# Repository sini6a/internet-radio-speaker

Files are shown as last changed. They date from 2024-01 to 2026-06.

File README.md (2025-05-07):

# Open Source Internet Radio Player

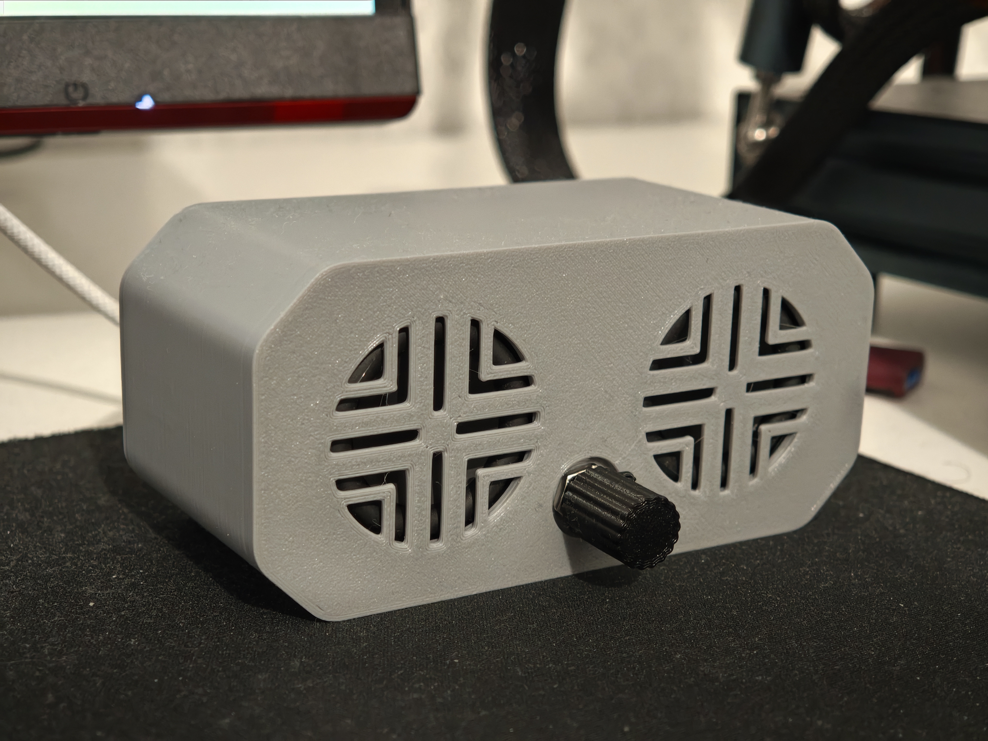
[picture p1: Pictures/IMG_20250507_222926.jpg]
Case #1

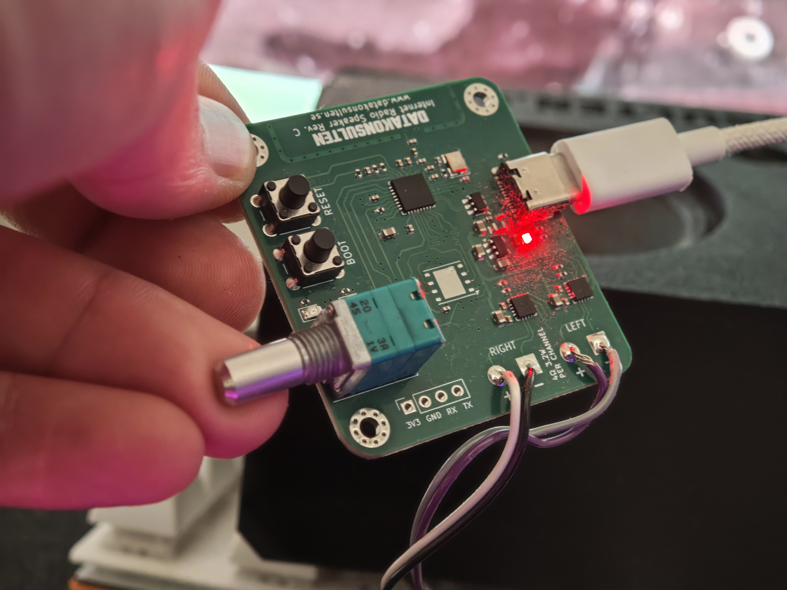
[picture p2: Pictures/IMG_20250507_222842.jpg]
PCB #1
  

## Hardware Specifications

- **Microcontroller:** ESP32-C3
- **Power Supply:** 5V/0.5A (USB Type-C, ~2.5W)
- **Flash Memory:** 4Mbit QSPI (on-chip)
- **Antenna:** Integrated PCB antenna
- **Controls:** Power switch and analog volume potentiometer
- **Audio Output:** Dual speaker output (3.2W max per channel)
- **Indicators:** 3x LEDs (Wi-Fi, Playback, Power)

## Description

This project is a compact, ESP32-C3-based Internet Radio Player designed for ease of use and straightforward integration. The device supports Wi-Fi streaming of MP3 audio and includes basic control via a single potentiometer and button. Audio output is handled via I2S to a stereo amplifier. 

The hardware includes onboard status LEDs and is powered via USB Type-C. It's suitable for low-power audio streaming applications, DIY audio projects, or integration into custom enclosures.

## Features

- 2.4 GHz Wi-Fi support using the built-in PCB antenna
- Minimal controls for simple user interaction
- USB Type-C programming and power interface
- Stereo speaker output via digital I2S
- LED indicators for connection and playback status

## Firmware and Usage

The firmware is located in the `Firmware/` directory and is built using the Arduino framework. Upload it via the Arduino IDE or other compatible tools. 

### Initial Setup

1. Flash the firmware to the ESP32-C3.
2. On first boot, the device creates a Wi-Fi Access Point.
3. Connect to the AP to configure the Wi-Fi credentials and stream URL.
4. After setup, the device reboots into streaming mode.

## Status

- Current hardware revision is stable and has been tested.
- The device is functional and ready for personal assembly or integration.
- Further development (BLE config, web UI, OTA, etc.) is planned or ongoing.

## Contributions

Pull requests, issue reports, and improvements are welcome. Make sure to open issue before to discuss changes.

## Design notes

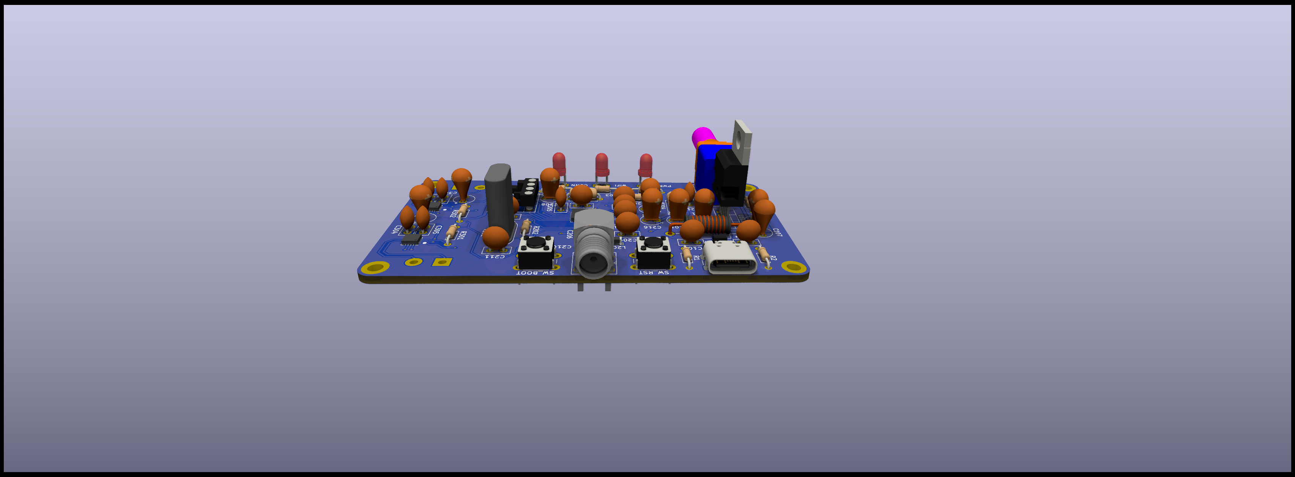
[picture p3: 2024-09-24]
Pictures/revision-2-1.png

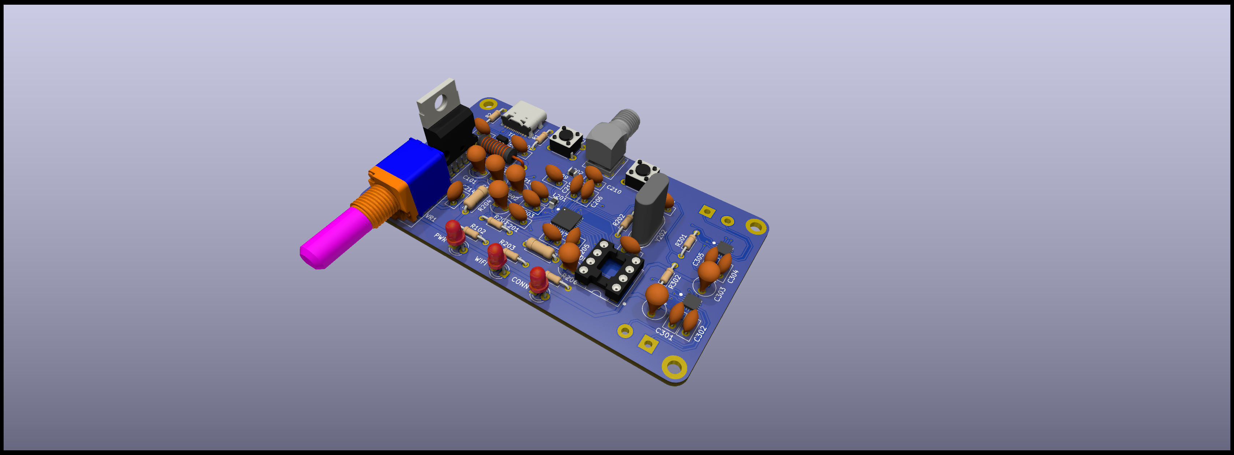
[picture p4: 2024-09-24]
Pictures/revision-2.png

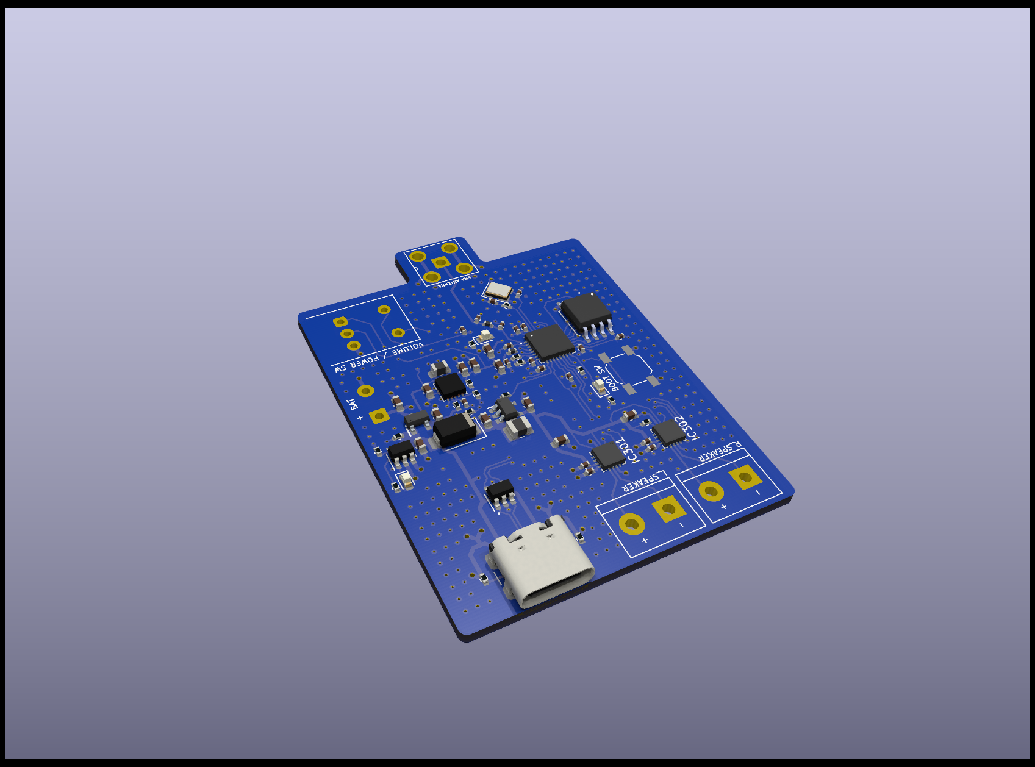
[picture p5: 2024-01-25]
Pictures/internet-radio-speaker-1.png

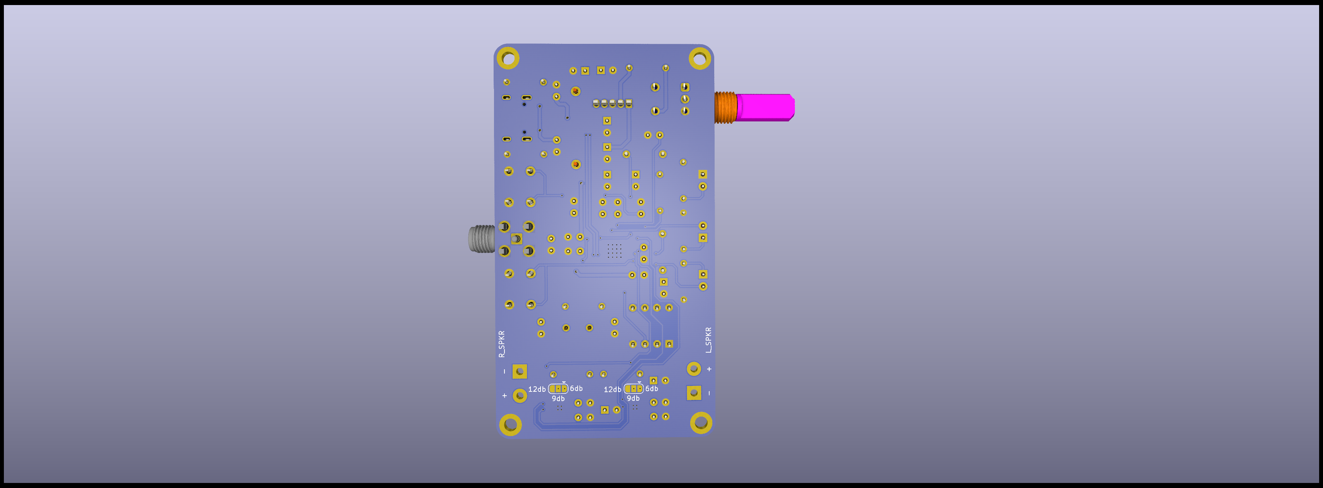
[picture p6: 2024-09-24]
Pictures/revision-2-2.png

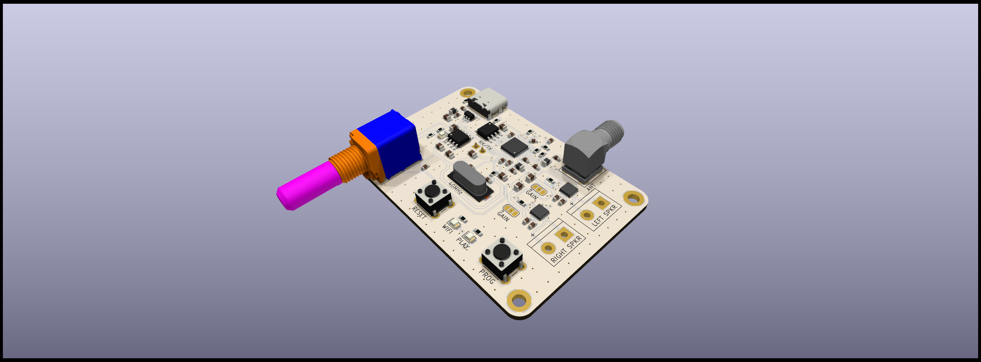
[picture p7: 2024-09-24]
Pictures/revision-3.png

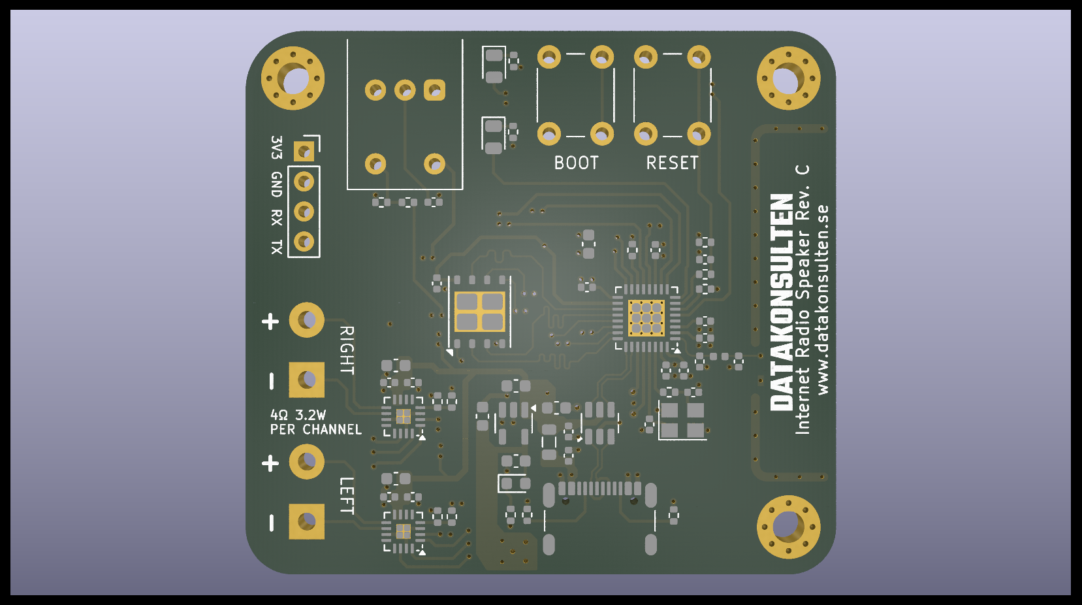
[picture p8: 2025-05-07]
Pictures/revision-4.png

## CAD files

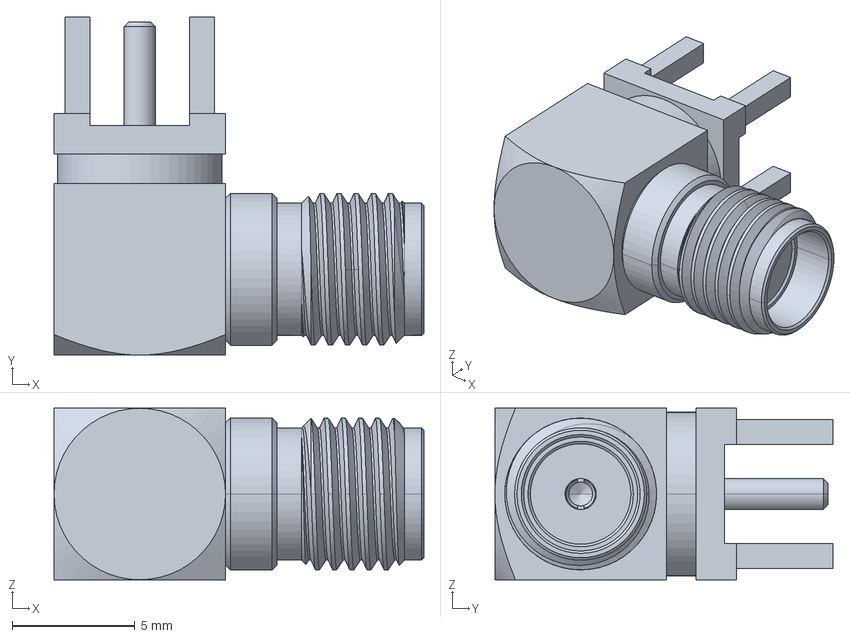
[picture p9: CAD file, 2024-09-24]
KiCad/3d/901-143-6RFX.stp
15.1 x 13.8 x 7.00 mm

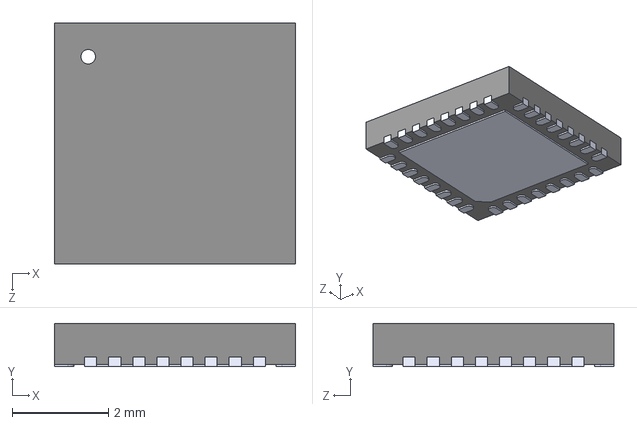
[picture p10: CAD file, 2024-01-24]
KiCad/3d/ESP32C3.step
5.00 x 0.9 x 5.00 mm

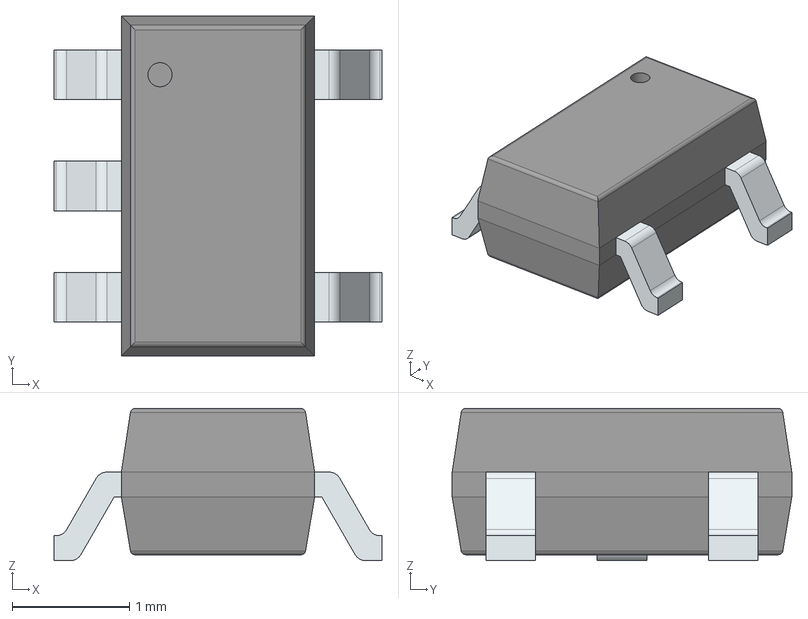
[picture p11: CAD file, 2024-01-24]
KiCad/3d/XC9141B33DMR-G.stp
2.80 x 2.90 x 1.30 mm
PinsArrayL
PinsArrayR

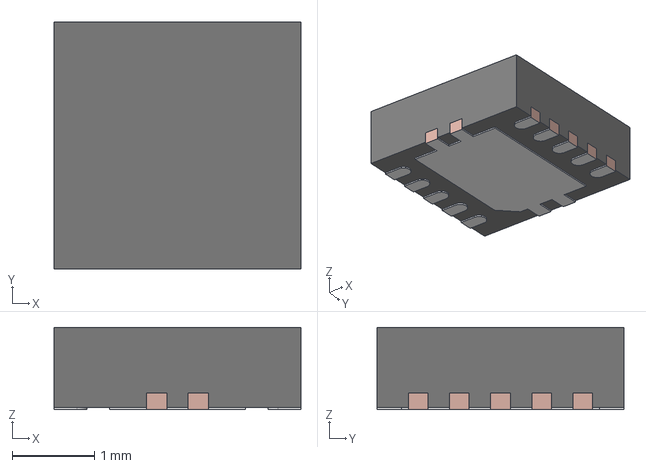
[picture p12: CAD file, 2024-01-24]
KiCad/3d/DRC0010J.stp
3.00 x 3.00 x 1.00 mm
BODY-SON
FRAME-DRC0010J

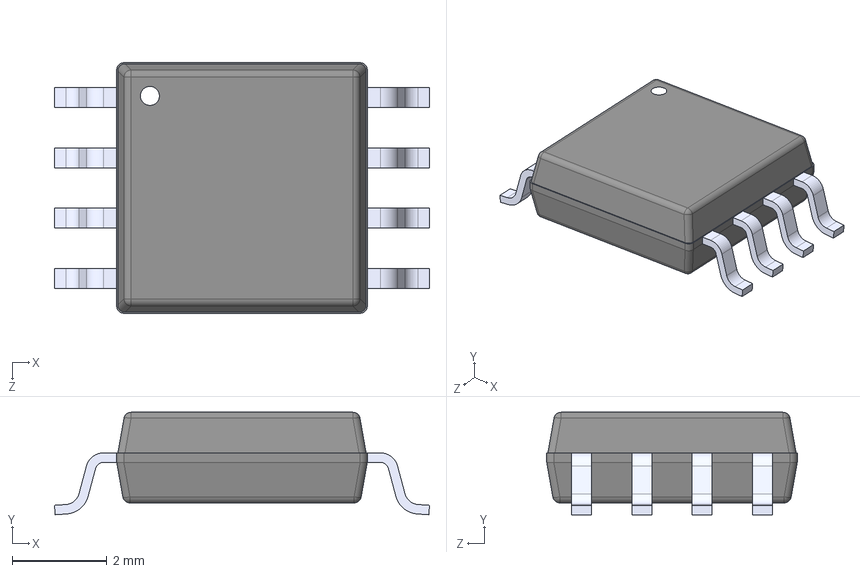
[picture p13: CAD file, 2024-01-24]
KiCad/3d/W25Q32JVSSIQ--3DModel-STEP-269445.STEP
7.90 x 2.16 x 5.28 mm

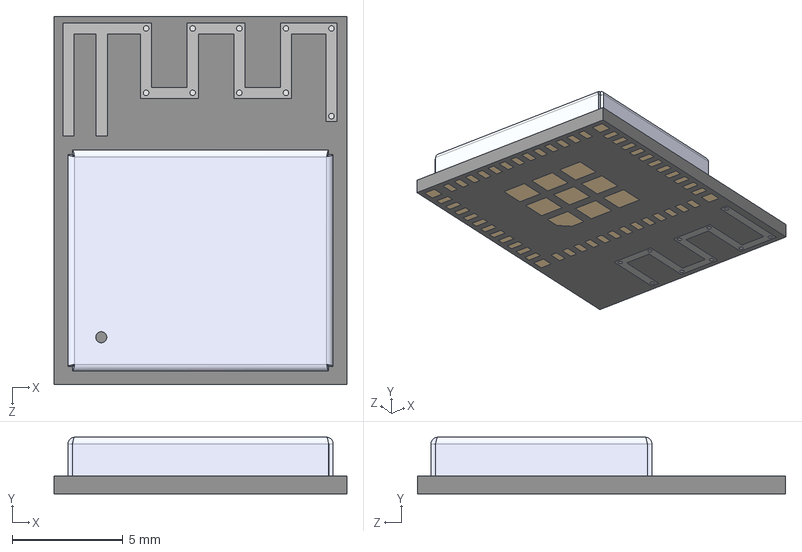
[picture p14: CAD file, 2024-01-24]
KiCad/3d/ESP32-C3-MINI-1-N4.step
13.2 x 2.55 x 16.6 mm

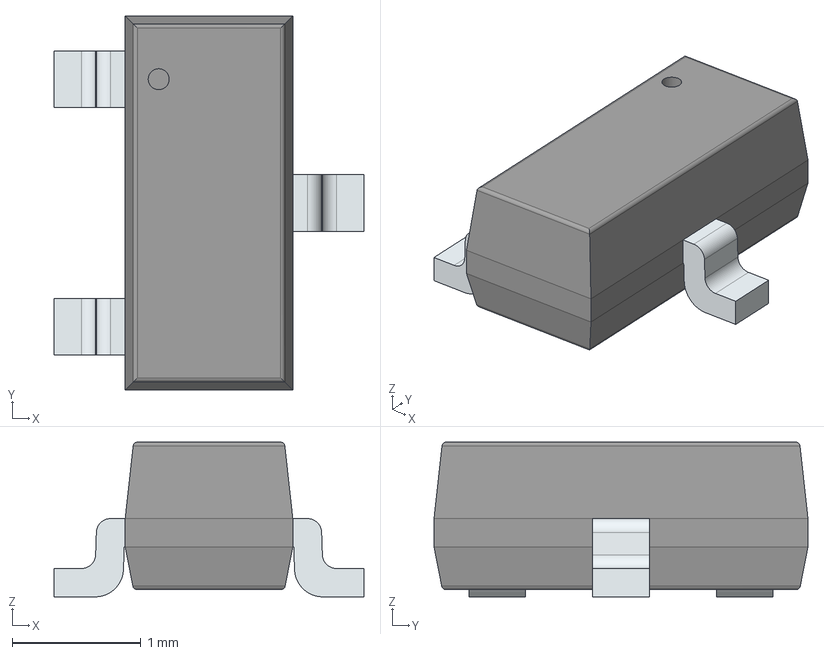
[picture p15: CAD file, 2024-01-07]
KiCad/3d/DMP1045U-7.stp
2.40 x 2.90 x 1.20 mm
PinsArrayL
FilletPinR

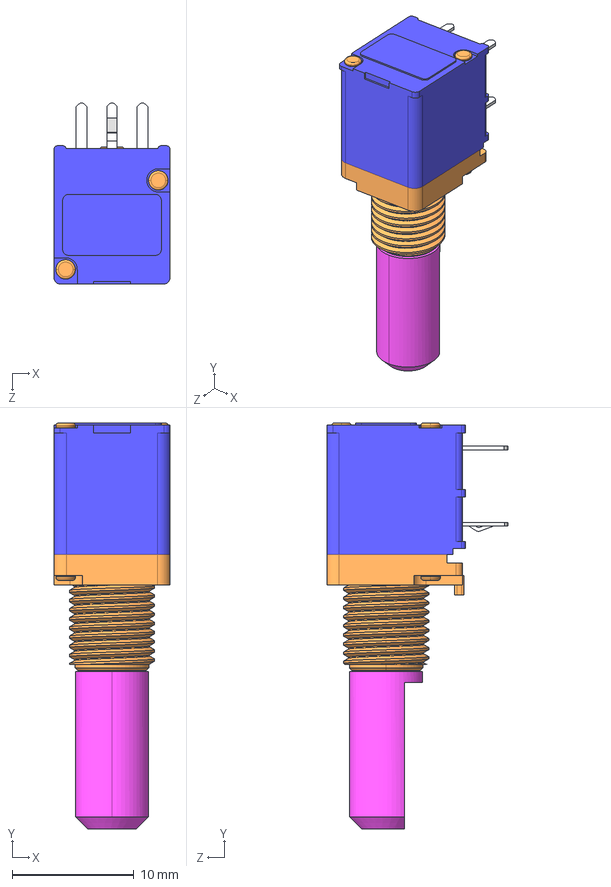
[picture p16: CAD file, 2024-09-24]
KiCad/3d/RK0971111-L20.STEP
9.50 x 33.3 x 14.8 mm

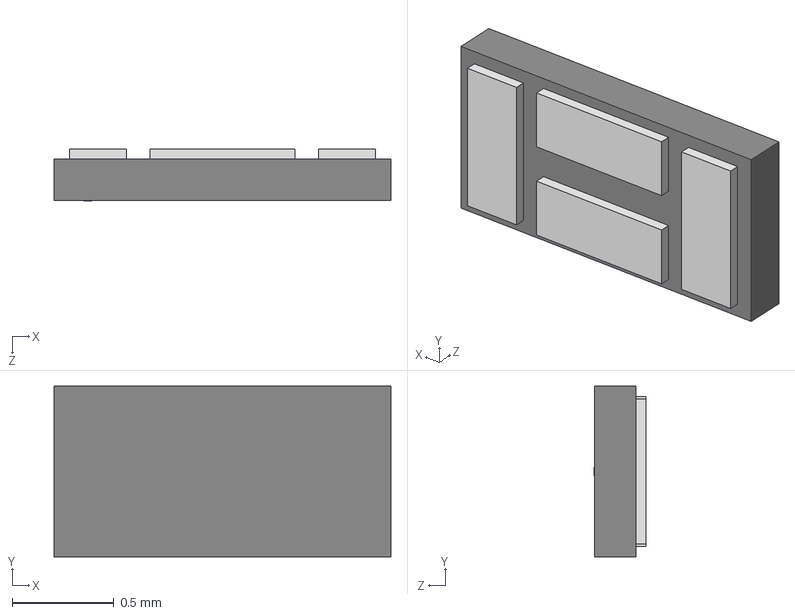
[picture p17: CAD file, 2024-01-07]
KiCad/3d/DLF162500LT-5028A1.stp
1.65 x 0.838 x 0.257 mm

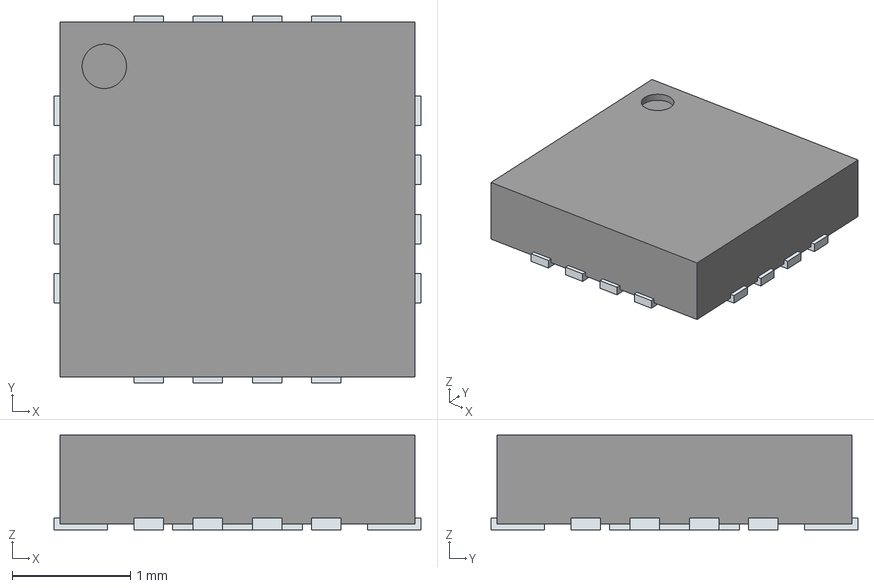
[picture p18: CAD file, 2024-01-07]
KiCad/3d/MAX98357AETE+T.stp
3.10 x 3.10 x 0.8 mm
ThermalPin
PinsArrayLR
PinsArrayTB

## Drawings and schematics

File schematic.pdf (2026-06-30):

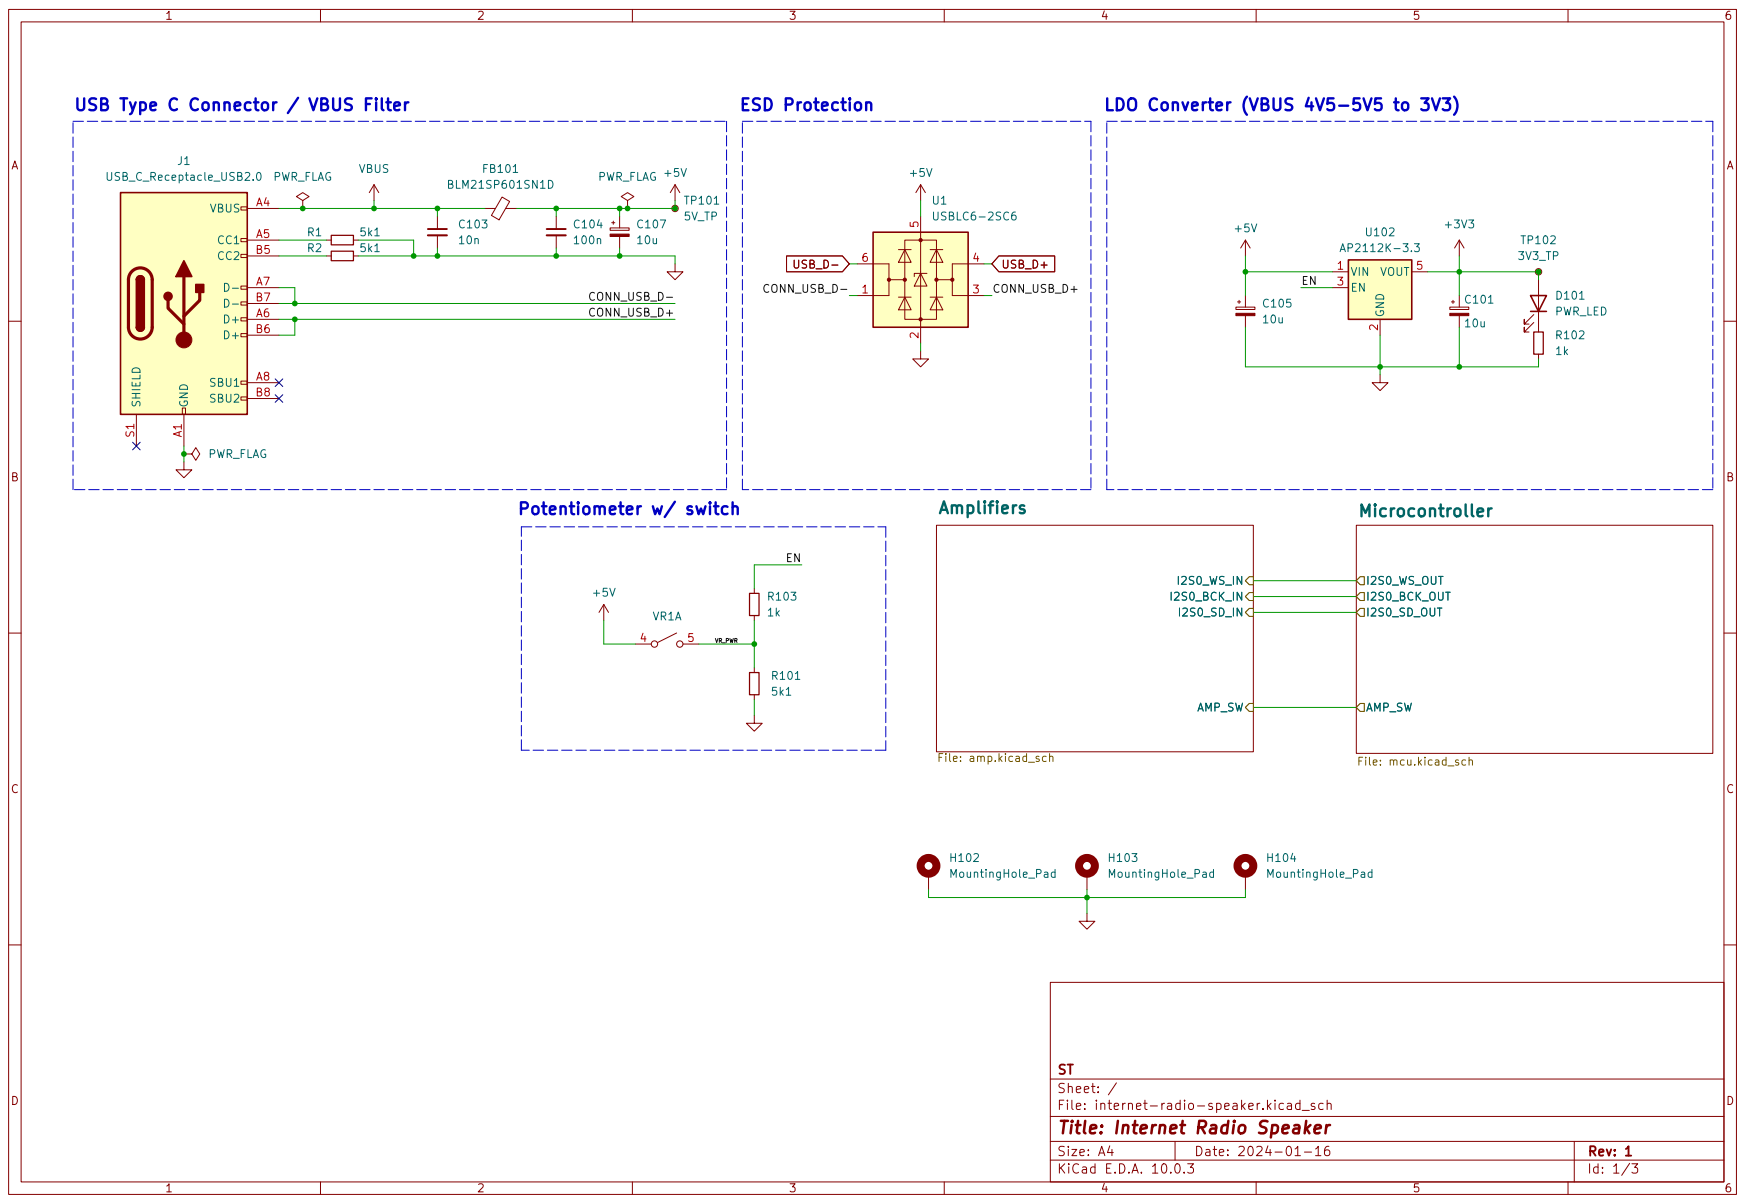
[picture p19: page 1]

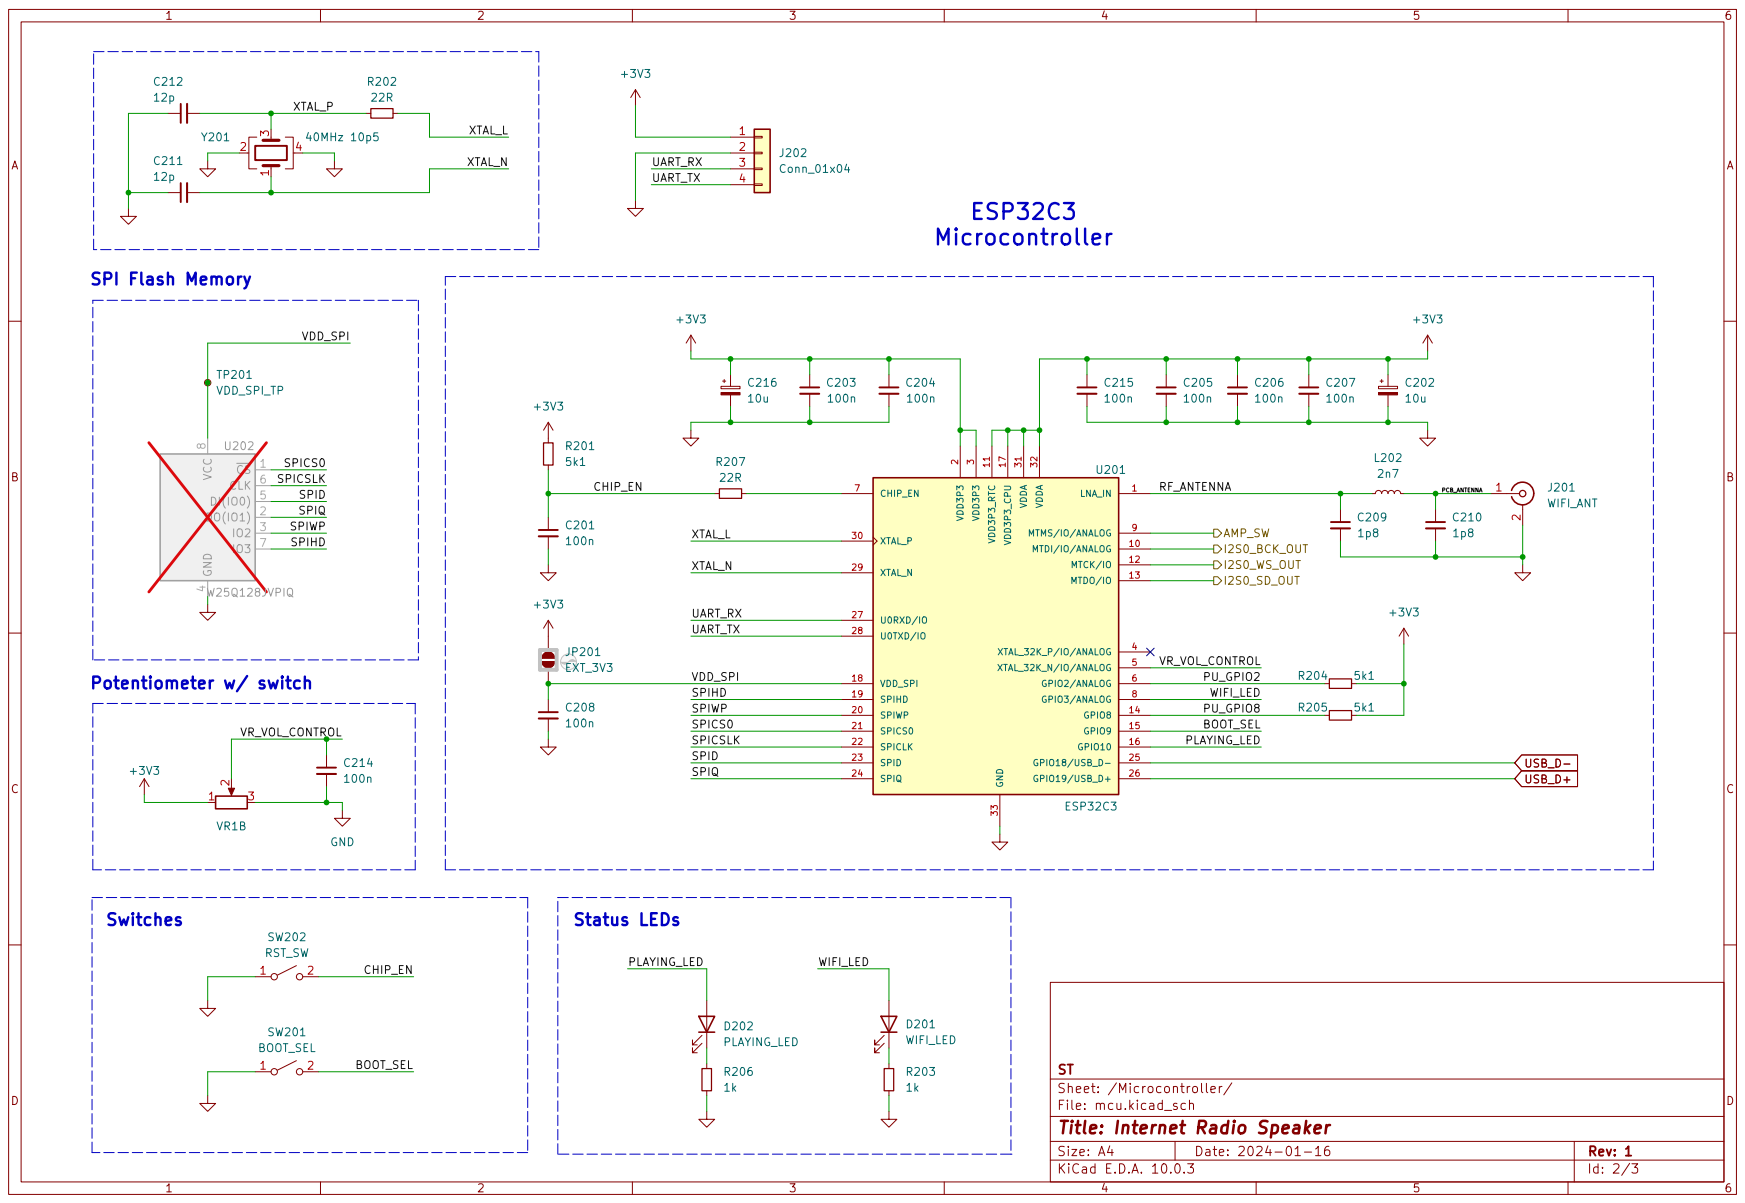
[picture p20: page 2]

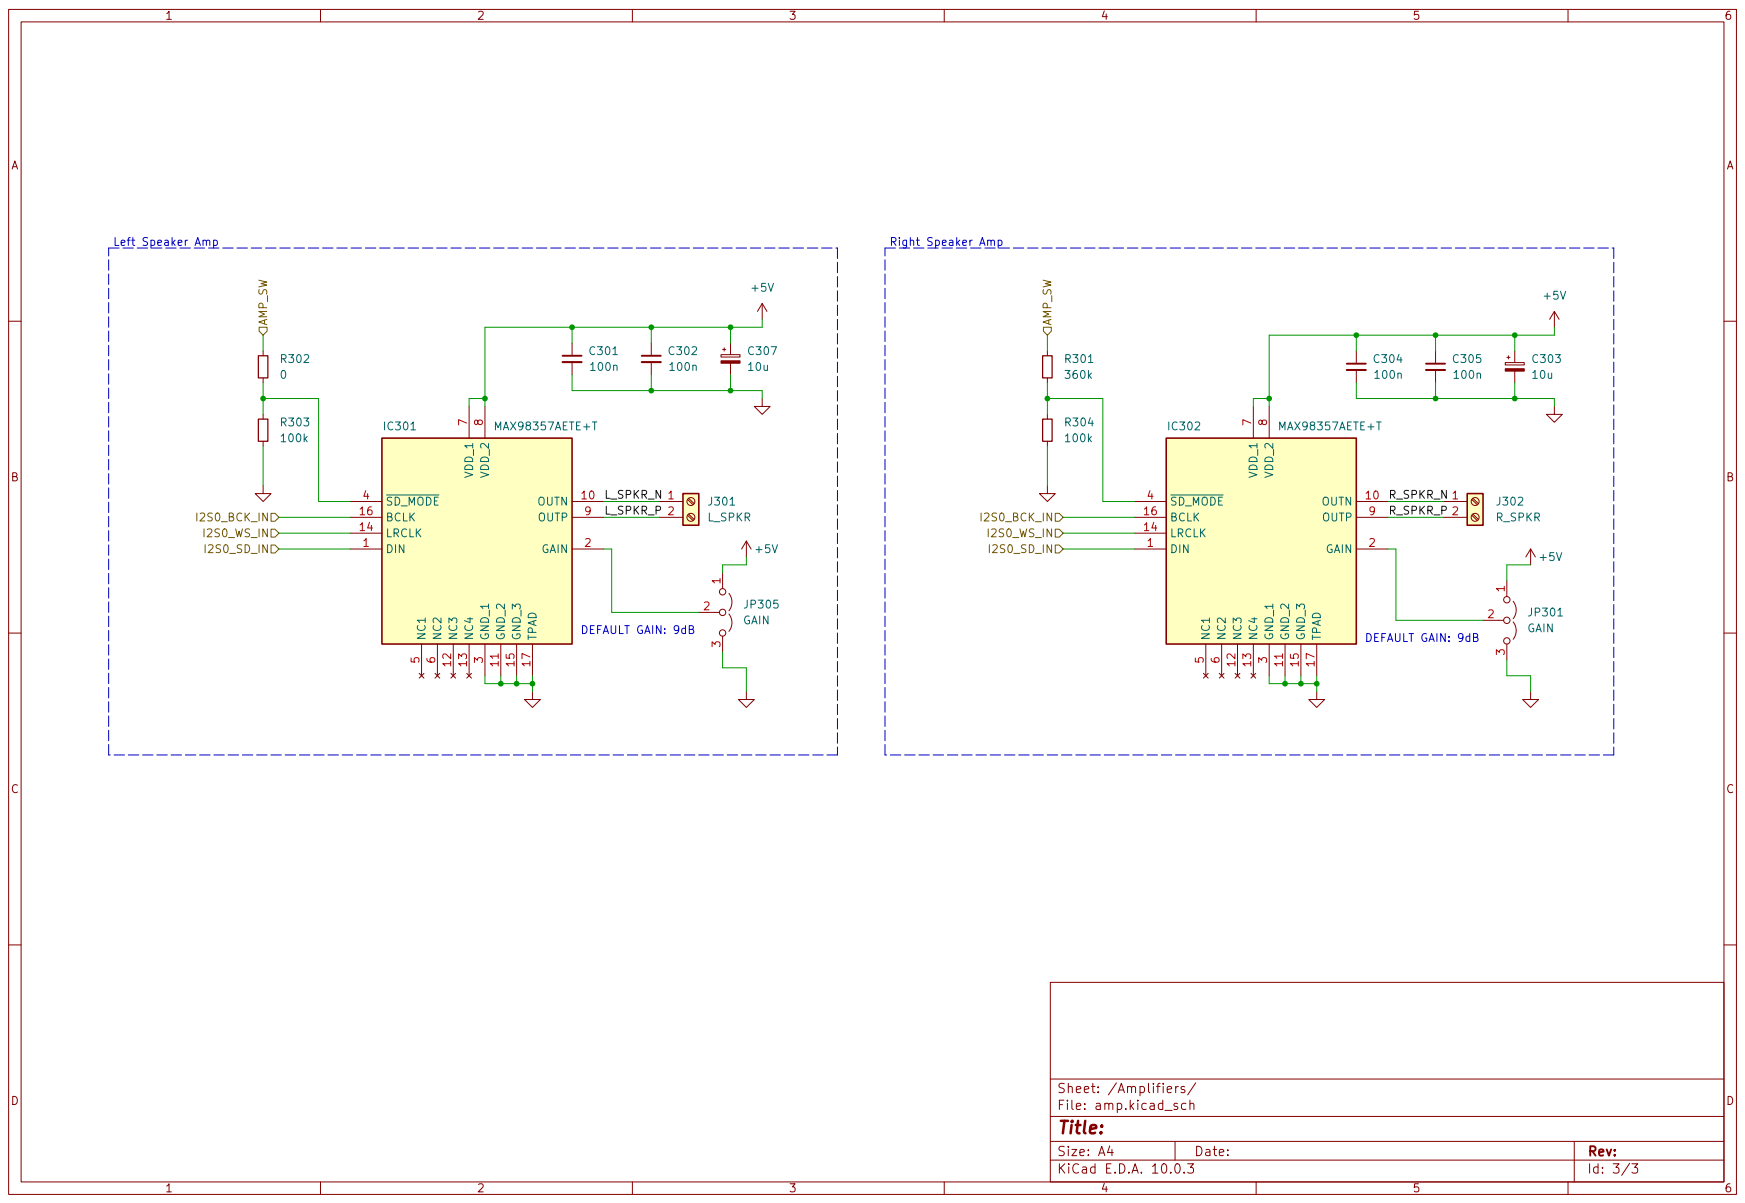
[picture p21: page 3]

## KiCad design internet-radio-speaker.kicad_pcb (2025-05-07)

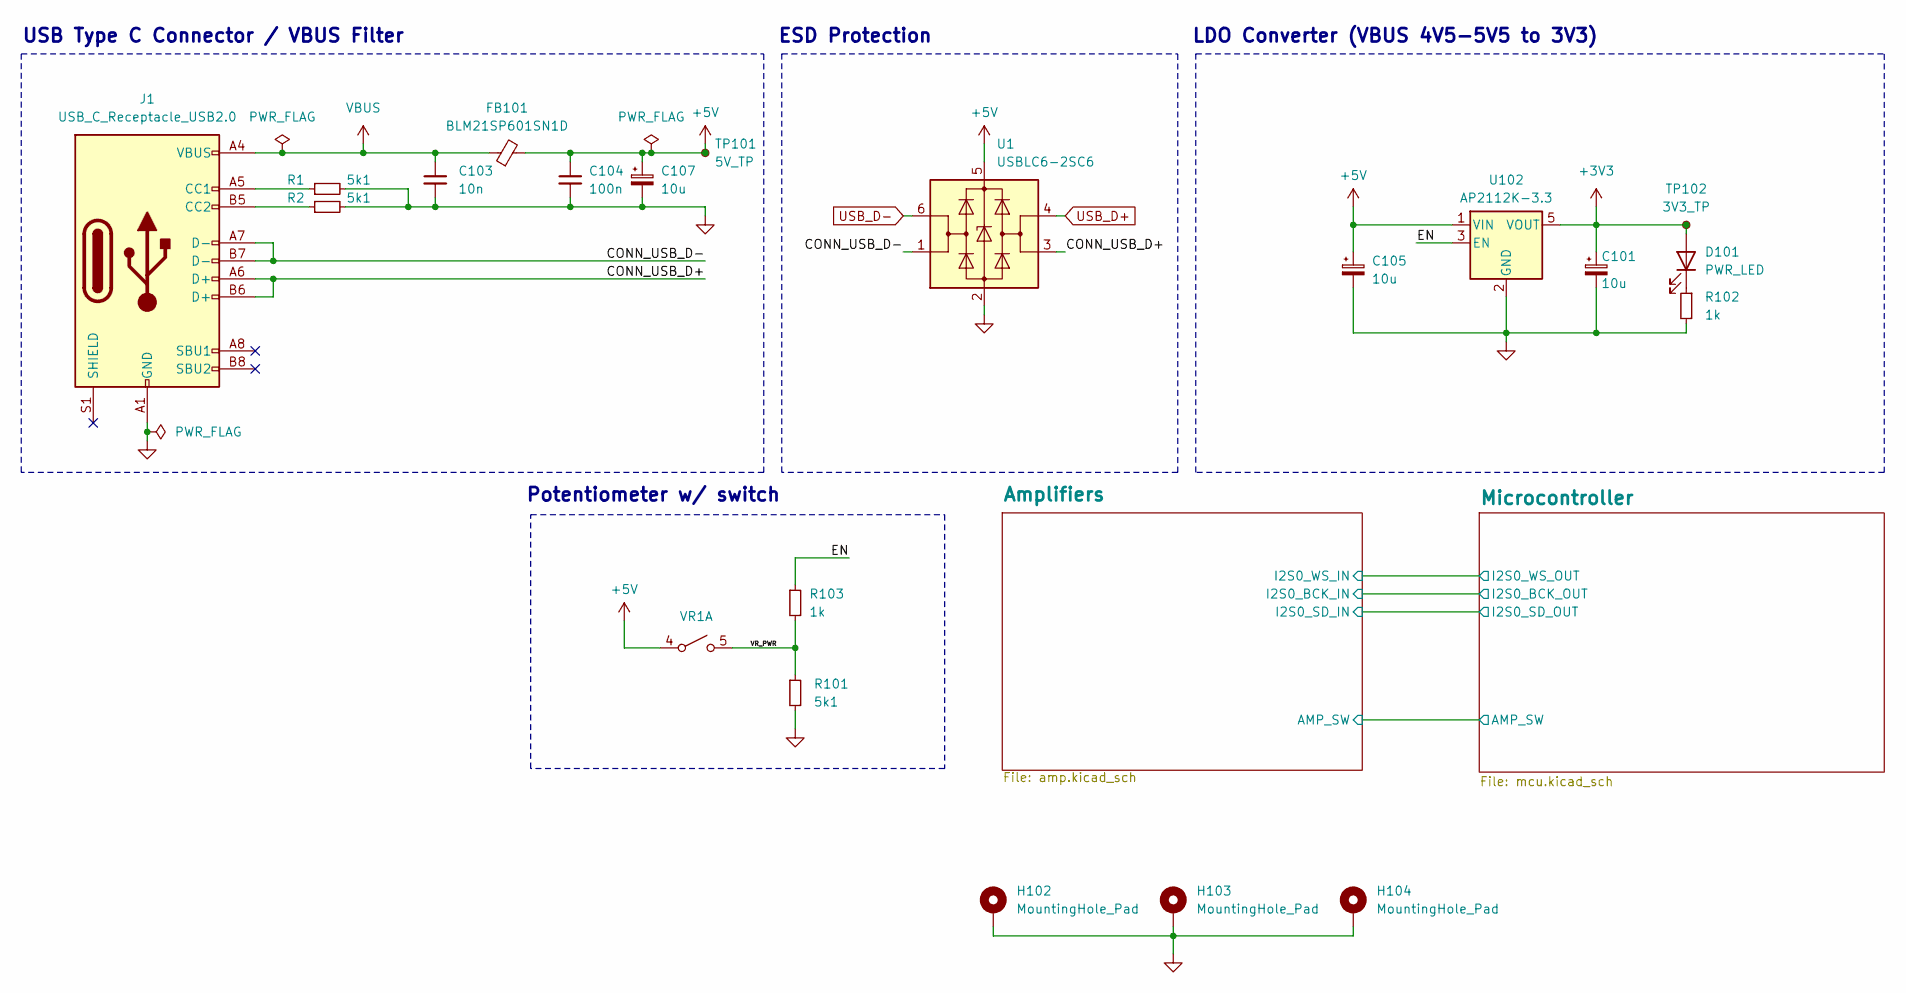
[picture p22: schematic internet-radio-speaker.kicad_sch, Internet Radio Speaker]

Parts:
C101, C105, C107: 10u; C_0603_1608Metric; JLCPCB Part # C96446
C103: 10n; C_0402_1005Metric; JLCPCB Part # C15195
C104: 100n; C_0402_1005Metric; JLCPCB Part # C1525
D101: PWR_LED; LED_0603_1608Metric; JLCPCB Part # C2286
FB101: BLM21SP601SN1D; L_0805_2012Metric; JLCPCB Part # C3716677
H102, H103, H104: MountingHole_Pad; MountingHole_2.7mm_M2.5_Pad_Via
J1: USB_C_Receptacle_USB2.0; USB_C_Receptacle_GCT_USB4105-xx-A_16P_TopMnt_Horizontal; JLCPCB Part # C2927038
R1, R2, R101: 5k1; R_0402_1005Metric; JLCPCB Part # C25905
R102, R103: 1k; R_0402_1005Metric; JLCPCB Part # C11702
TP101: 5V_TP; TestPoint_Pad_D1.5mm
TP102: 3V3_TP; TestPoint_Pad_D1.5mm
U1: USBLC6-2SC6; SOT-23-6; JLCPCB Part # C2687116
U102: AP2112K-3.3; SOT-23-5; JLCPCB Part # C51118
VR1: Potentiometer_Alps_RK0971111Z1P; JLCPCB Part # C2687318

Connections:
+3V3: C101.1, D101.2 (A), TP102.1, U102.5 (VOUT); also elsewhere on the board
+5V: C104.1, C105.1, C107.1, FB101.2, TP101.1, U1.5 (VBUS), U102.1 (VIN), VR1.4 (A); also elsewhere on the board
/CONN_USB_D+: J1.A6 (D+), J1.B6 (D+), U1.3 (I/O2)
/CONN_USB_D-: J1.A7 (D-), J1.B7 (D-), U1.1 (I/O1)
/EN: R103.1, U102.3 (EN)
/VR_PWR: R101.1, R103.2, VR1.5 (B)
GND: C101.2, C103.2, C104.2, C105.2, C107.2, H102.1, H103.1, H104.1, J1.A1 (GND), J1.A12 (GND), J1.B1 (GND), J1.B12 (GND), R1.2, R2.2, R101.2, R102.2, U1.2 (GND), U102.2 (GND); also elsewhere on the board
unnamed: D101.1 (K), R102.1
unnamed: J1.A5 (CC1), R1.1
unnamed: J1.B5 (CC2), R2.1
USB_D+: U1.4 (I/O2); also elsewhere on the board
USB_D-: U1.6 (I/O1); also elsewhere on the board
VBUS: C103.1, FB101.1, J1.A4 (VBUS), J1.A9 (VBUS), J1.B4 (VBUS), J1.B9 (VBUS)

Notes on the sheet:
ESD Protection
USB Type C Connector / VBUS Filter
Potentiometer w/ switch
LDO Converter (VBUS 4V5-5V5 to 3V3)

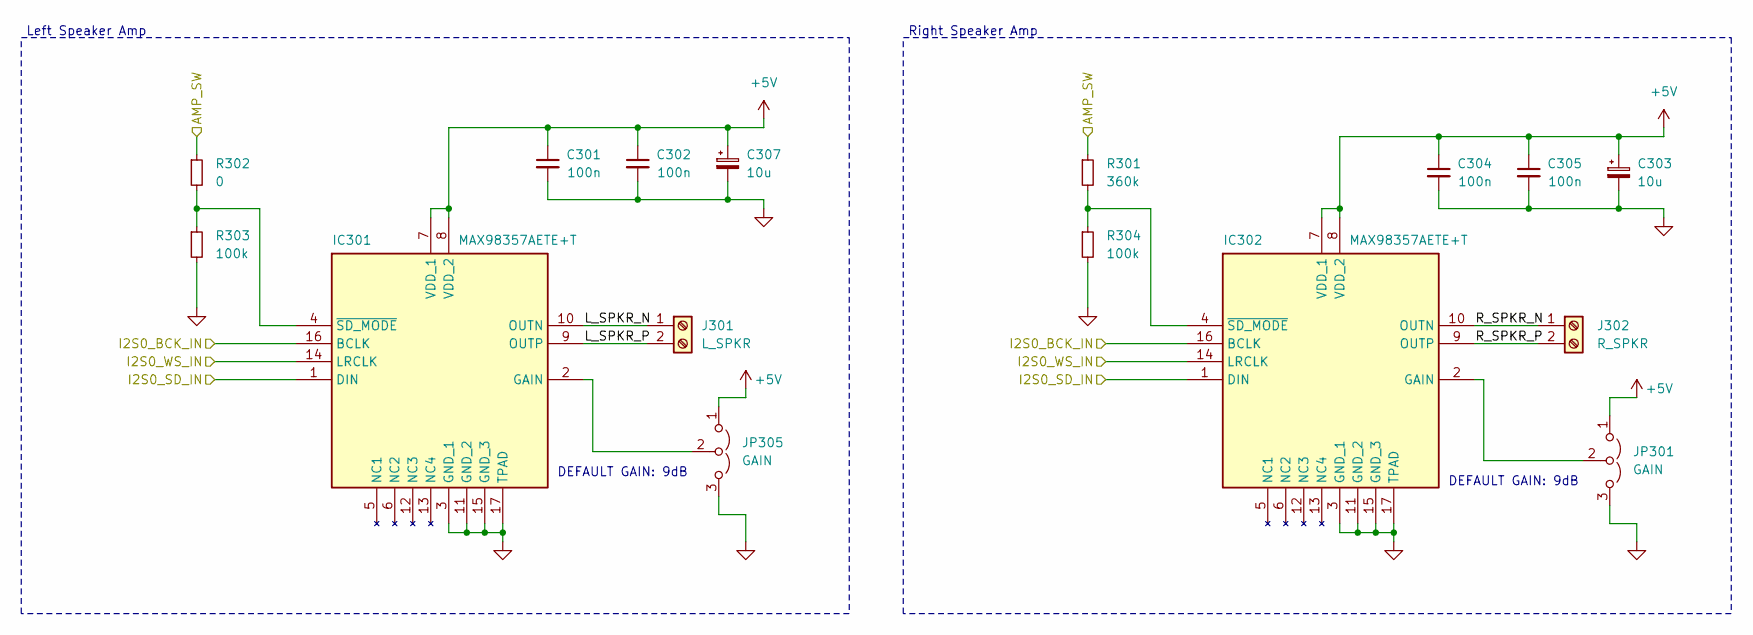
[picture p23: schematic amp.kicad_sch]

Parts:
C301, C302, C304, C305: 100n; C_0402_1005Metric; JLCPCB Part # C1525
C303, C307: 10u; C_0603_1608Metric; JLCPCB Part # C96446
IC301, IC302: MAX98357AETE+T; TQFN-16-1EP_3x3mm_P0.5mm_EP1.23x1.23mm_ThermalVias; JLCPCB Part # C910544
J301: L_SPKR; TerminalBlock_bornier-2_P5.08mm
J302: R_SPKR; TerminalBlock_bornier-2_P5.08mm
JP301, JP305: GAIN; SolderJumper-3_P1.3mm_Open_RoundedPad1.0x1.5mm
R301: 360k; R_0402_1005Metric; JLCPCB Part # C45956
R302: 0; R_0402_1005Metric; JLCPCB Part # C17168
R303, R304: 100k; R_0402_1005Metric; JLCPCB Part # C25741

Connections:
+5V: C301.1, C302.1, C303.1, C304.1, C305.1, C307.1, IC301.7 (VDD_1), IC301.8 (VDD_2), IC302.7 (VDD_1), IC302.8 (VDD_2), JP301.1 (A), JP305.1 (A); also elsewhere on the board
/Amplifiers/AMP_SW: R301.1, R302.1; also elsewhere on the board
/Amplifiers/I2S0_BCK_IN: IC301.16 (BCLK), IC302.16 (BCLK); also elsewhere on the board
/Amplifiers/I2S0_SD_IN: IC301.1 (DIN), IC302.1 (DIN); also elsewhere on the board
/Amplifiers/I2S0_WS_IN: IC301.14 (LRCLK), IC302.14 (LRCLK); also elsewhere on the board
/Amplifiers/L_SPKR_N: IC301.10 (OUTN), J301.1
/Amplifiers/L_SPKR_P: IC301.9 (OUTP), J301.2
/Amplifiers/R_SPKR_N: IC302.10 (OUTN), J302.1
/Amplifiers/R_SPKR_P: IC302.9 (OUTP), J302.2
GND: C301.2, C302.2, C303.2, C304.2, C305.2, C307.2, IC301.3 (GND_1), IC301.11 (GND_2), IC301.15 (GND_3), IC301.17 (TPAD), IC302.3 (GND_1), IC302.11 (GND_2), IC302.15 (GND_3), IC302.17 (TPAD), JP301.3 (B), JP305.3 (B), R303.2, R304.2; also elsewhere on the board
unnamed: IC301.2 (GAIN), JP305.2 (C)
unnamed: IC301.4 (~SD_MODE), R302.2, R303.1
unnamed: IC302.2 (GAIN), JP301.2 (C)
unnamed: IC302.4 (~SD_MODE), R301.2, R304.1

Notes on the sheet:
Left Speaker Amp
Right Speaker Amp
DEFAULT GAIN: 9dB

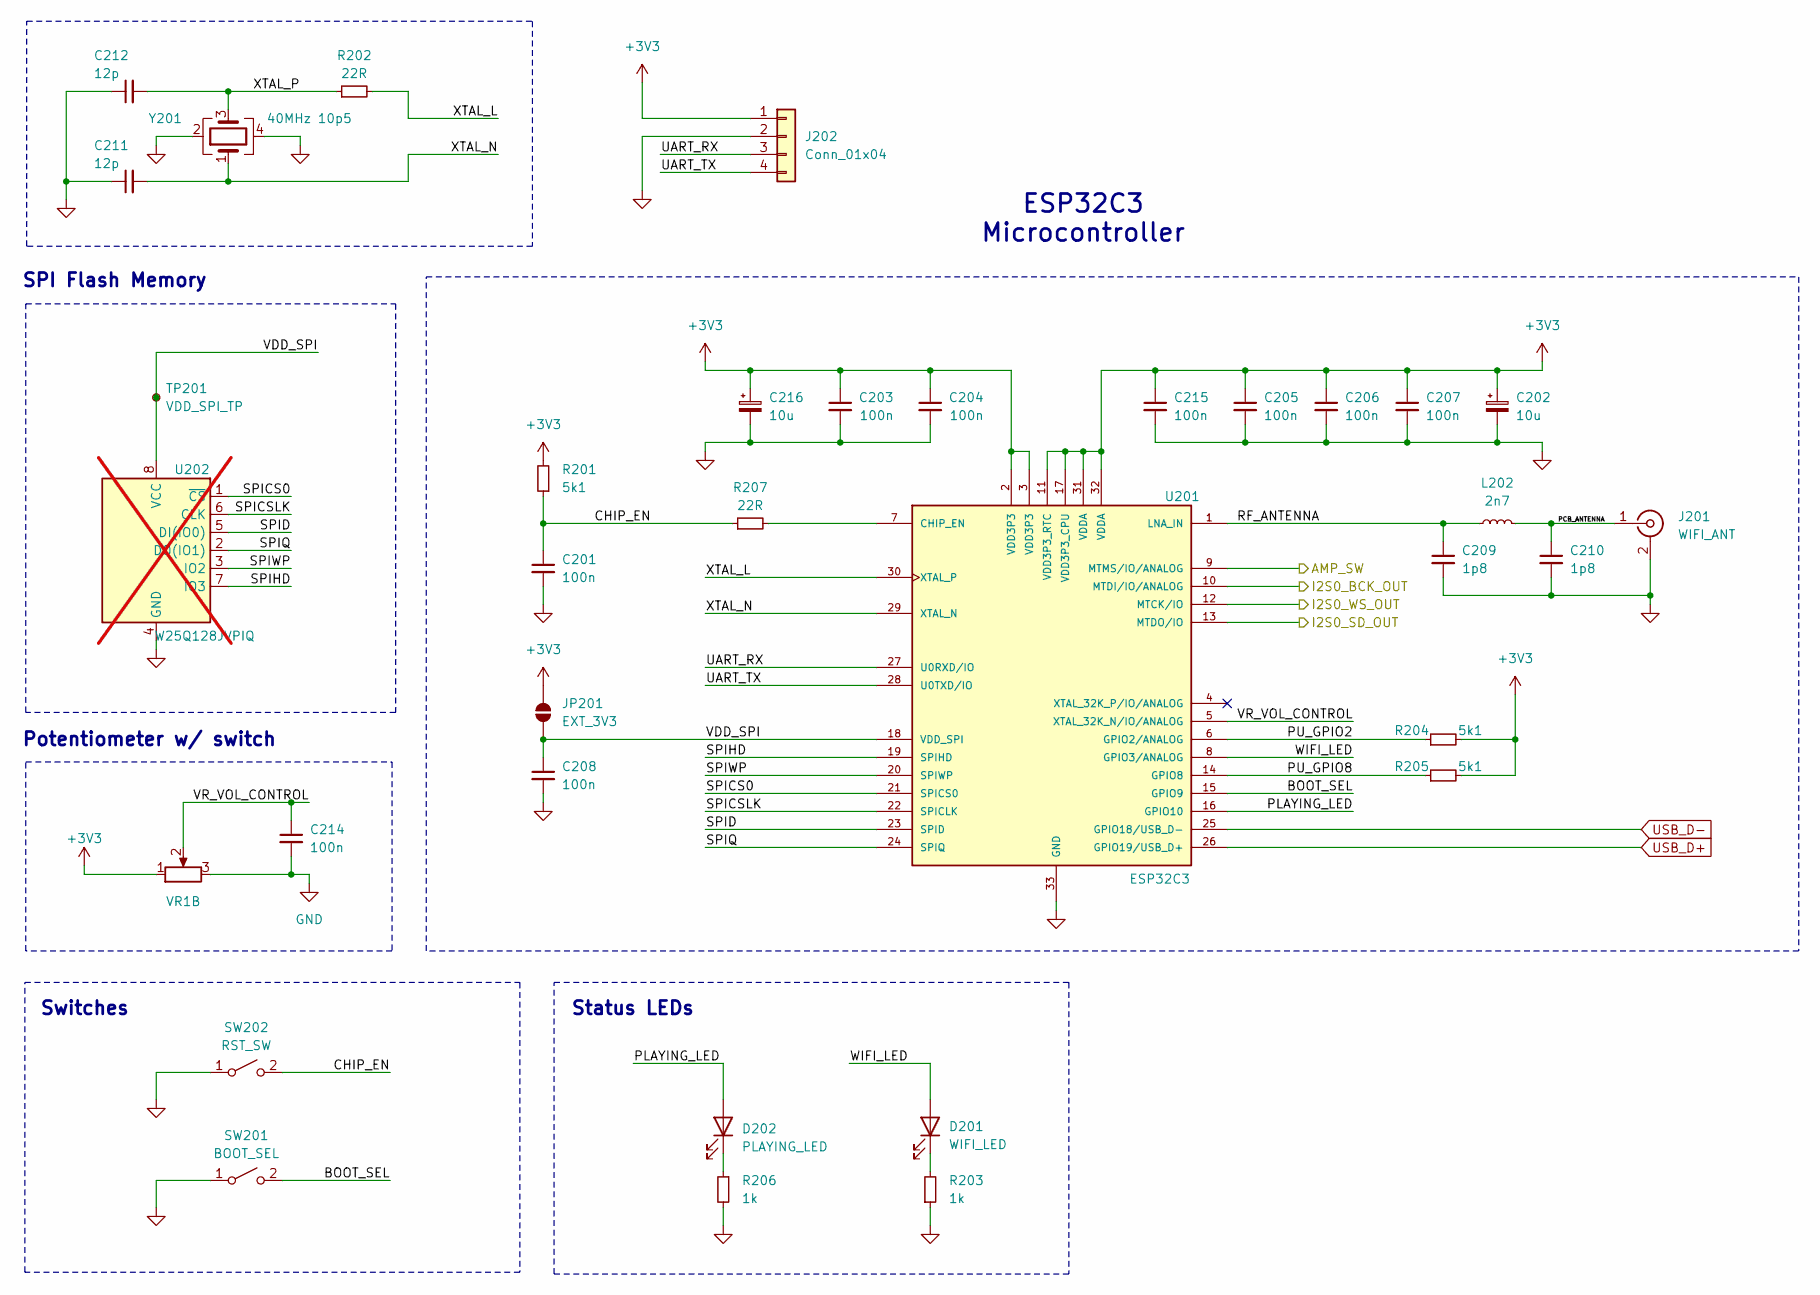
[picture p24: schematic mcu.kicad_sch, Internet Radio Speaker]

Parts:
C201, C203, C204, C205, C206, C207, C208, C214, C215: 100n; C_0402_1005Metric; JLCPCB Part # C1525
C202, C216: 10u; C_0603_1608Metric; JLCPCB Part # C96446
C209, C210: 1p8; C_0402_1005Metric; JLCPCB Part # C1553
C211, C212: 12p; C_0402_1005Metric; JLCPCB Part # C1547
D201: WIFI_LED; LED_0805_2012Metric; JLCPCB Part # C2297
D202: PLAYING_LED; LED_0805_2012Metric; JLCPCB Part # C2296
J201: WIFI_ANT; Texas_SWRA117D_2.4GHz_Right; LCSC C3174435
J202: Conn_01x04; PinSocket_1x04_P2.54mm_Vertical
JP201: EXT_3V3; SolderJumper-2_P1.3mm_Open_RoundedPad1.0x1.5mm
L202: 2n7; L_0402_1005Metric; JLCPCB Part # C77108
R201, R204, R205: 5k1; R_0402_1005Metric; JLCPCB Part # C25905
R202, R207: 22R; R_0402_1005Metric; JLCPCB Part # C25092
R203, R206: 1k; R_0402_1005Metric; JLCPCB Part # C11702
SW201: BOOT_SEL; SW_PUSH_6mm; JLCPCB Part # C2889001
SW202: RST_SW; SW_PUSH_6mm; JLCPCB Part # C2889001
TP201: VDD_SPI_TP; TestPoint_Pad_D1.5mm
U201: ESP32C3; HVQFN-32-1EP_5x5mm_P0.5mm_EP3.1x3.1mm_ThermalVias; LCSC C2858491
U202: W25Q128JVPIQ; WSON-8-1EP_6x5mm_P1.27mm_EP3.4x4.3mm; JLCPCB Part # C190862; not fitted
VR1: Potentiometer_Alps_RK0971111Z1P; JLCPCB Part # C2687318
Y201: 40MHz 10p5; Crystal_SMD_3225-4Pin_3.2x2.5mm; JLCPCB Part # C19191260

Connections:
+3V3: C202.1, C203.1, C204.1, C205.1, C206.1, C207.1, C215.1, C216.1, J202.1, JP201.2 (B), R201.2, R204.2, R205.2, U201.2 (VDD3P3), U201.3 (VDD3P3), U201.11 (VDD3P3_RTC), U201.17 (VDD3P3_CPU), U201.31 (VDDA), U201.32 (VDDA), VR1.1; also elsewhere on the board
/Amplifiers/AMP_SW: U201.9 (MTMS/IO/ANALOG); also elsewhere on the board
/Amplifiers/I2S0_BCK_IN: U201.10 (MTDI/IO/ANALOG); also elsewhere on the board
/Amplifiers/I2S0_SD_IN: U201.13 (MTDO/IO); also elsewhere on the board
/Amplifiers/I2S0_WS_IN: U201.12 (MTCK/IO); also elsewhere on the board
/Microcontroller/BOOT_SEL: SW201.2 (B), U201.15 (GPIO9)
/Microcontroller/CHIP_EN: C201.1, R201.1, R207.1, SW202.2 (B)
/Microcontroller/PCB_ANTENNA: C210.1, J201.1 (In), L202.2
/Microcontroller/PLAYING_LED: D202.2 (A), U201.16 (GPIO10)
/Microcontroller/PU_GPIO2: R204.1, U201.6 (GPIO2/ANALOG)
/Microcontroller/PU_GPIO8: R205.1, U201.14 (GPIO8)
/Microcontroller/RF_ANTENNA: C209.1, L202.1, U201.1 (LNA_IN)
/Microcontroller/SPICS0: U201.21 (SPICS0), U202.1 (~CS)
/Microcontroller/SPICSLK: U201.22 (SPICLK), U202.6 (CLK)
/Microcontroller/SPID: U201.23 (SPID), U202.5 (DI(IO0))
/Microcontroller/SPIHD: U201.19 (SPIHD), U202.7 (IO3)
/Microcontroller/SPIQ: U201.24 (SPIQ), U202.2 (DO(IO1))
/Microcontroller/SPIWP: U201.20 (SPIWP), U202.3 (IO2)
/Microcontroller/UART_RX: J202.3, U201.27 (U0RXD/IO)
/Microcontroller/UART_TX: J202.4, U201.28 (U0TXD/IO)
/Microcontroller/VDD_SPI: C208.1, JP201.1 (A), TP201.1, U201.18 (VDD_SPI), U202.8 (VCC)
/Microcontroller/VR_VOL_CONTROL: C214.1, U201.5 (XTAL_32K_N/IO/ANALOG), VR1.2
/Microcontroller/WIFI_LED: D201.2 (A), U201.8 (GPIO3/ANALOG)
/Microcontroller/XTAL_L: R202.2, U201.30 (XTAL_P)
/Microcontroller/XTAL_N: C211.2, U201.29 (XTAL_N), Y201.1
/Microcontroller/XTAL_P: C212.2, R202.1, Y201.3
GND: C201.2, C202.2, C203.2, C204.2, C205.2, C206.2, C207.2, C208.2, C209.2, C210.2, C211.1, C212.1, C214.2, C215.2, C216.2, J201.2 (Ext), J202.2, R203.1, R206.2, SW201.1 (A), SW202.1 (A), U201.33 (GND), U202.4 (GND), VR1.3, Y201.2, Y201.4; also elsewhere on the board
unnamed: D201.1 (K), R203.2
unnamed: D202.1 (K), R206.1
unnamed: R207.2, U201.7 (CHIP_EN)
USB_D+: U201.26 (GPIO19/USB_D+); also elsewhere on the board
USB_D-: U201.25 (GPIO18/USB_D-); also elsewhere on the board

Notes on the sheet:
SPI Flash Memory
Status LEDs
Potentiometer w/ switch
Switches
ESP32C3 Microcontroller

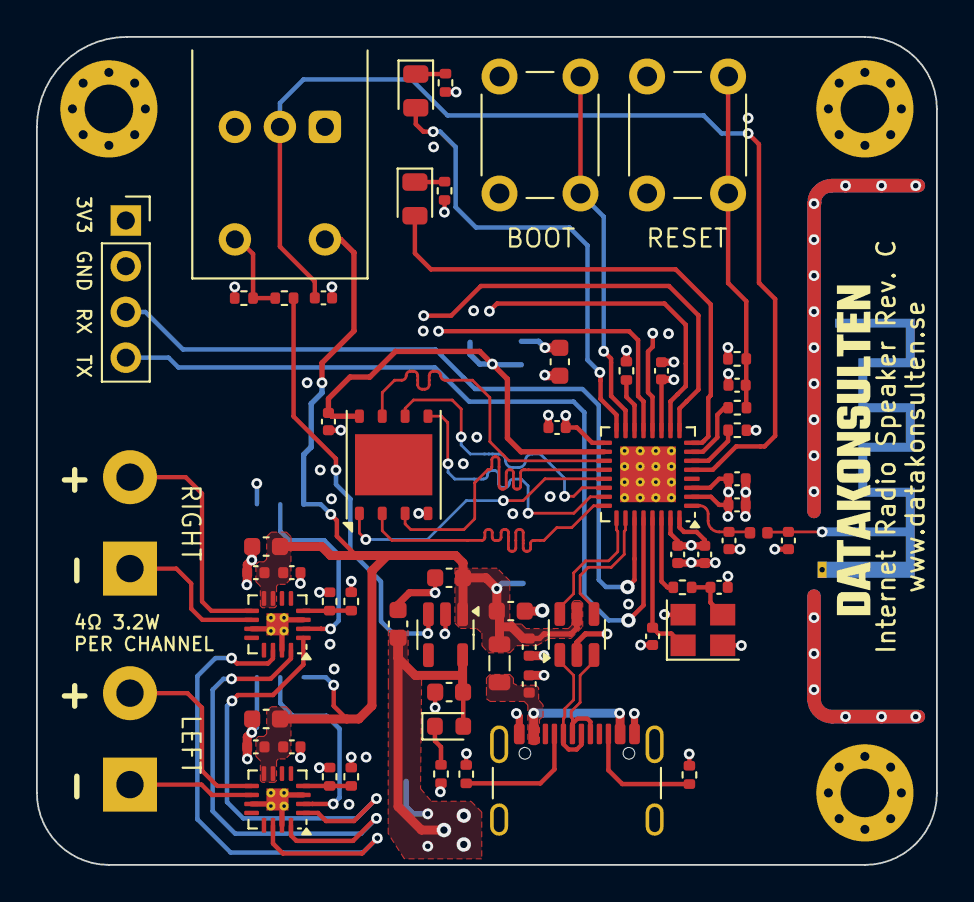
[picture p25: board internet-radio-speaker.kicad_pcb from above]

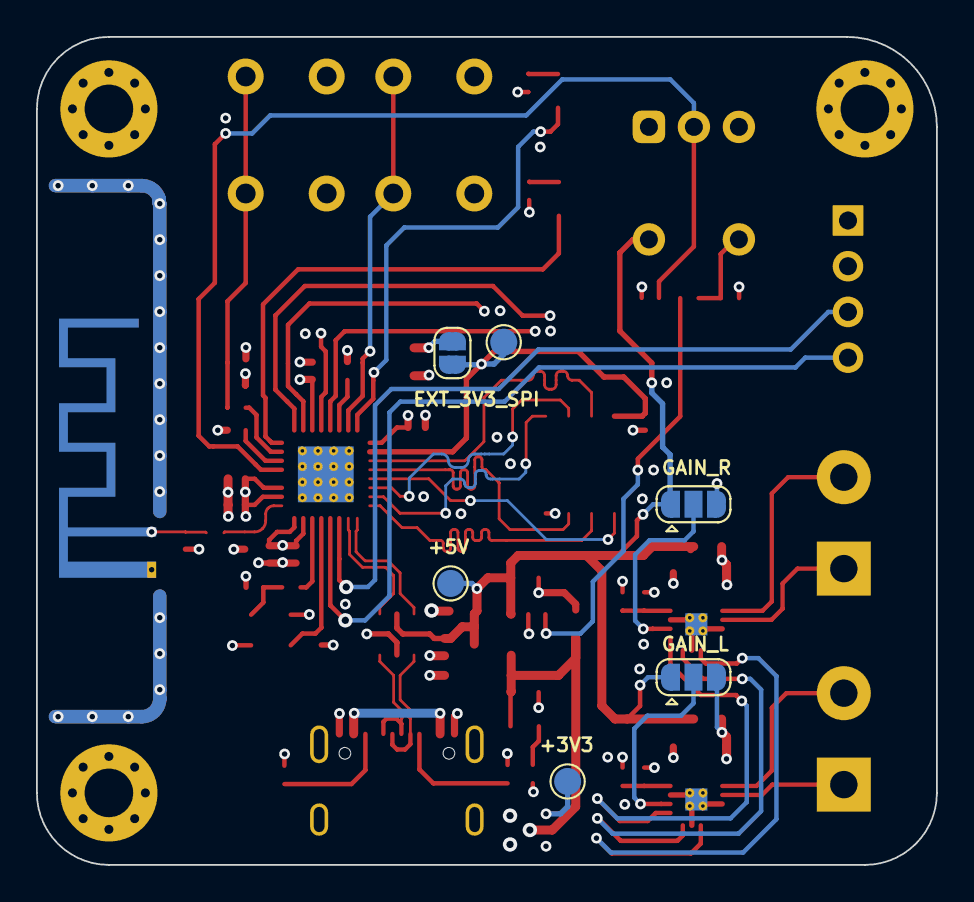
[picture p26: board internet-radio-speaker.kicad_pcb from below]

Board: 4 copper layers, 50.0 x 46.0 mm, 71 parts (7 on the bottom side), 49 nets.

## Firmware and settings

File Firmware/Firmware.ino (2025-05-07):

#define HELIX_FEATURE_AUDIO_CODEC_AAC_SBR
#define AAC_ENABLE_SBR
#define JSON_CONFIG_FILE "/configuration.json"

#include <WiFi.h>
#include <FS.h>
#include <LittleFS.h>
#include <WiFiManager.h>
#include <ArduinoJson.h>
#include "AudioTools.h"
#include "AudioTools/AudioCodecs/CodecMP3Helix.h"

// Constants and Pins
const int AMP_CONTROL_PIN = 4;  // Amplifier control pin (HIGH = ON)
const int WIFI_LED_PIN = 3;     // WiFi status LED
const int MUSIC_LED_PIN = 10;   // Music playing LED
const int VOLUME_CONTROL_PIN = 1;
const int BUTTON_PIN = 9;       // Button GPIO pin
const unsigned long HOLD_TIME = 3000; // Time to hold button for formatting (ms)

// Globals
bool shouldSaveConfig = false;
char streamURL[128] = "http://hyades.shoutca.st:8072/stream.mp3";
WiFiManager wm;
WiFiManagerParameter customTextBox("key_text", "Enter stream URL", streamURL, 128);

// Button Variables
unsigned long buttonPressTime = 0;
bool isFormatting = false;

// Audio Components
URLStream url;
I2SStream i2s;
VolumeStream volume(i2s);
EncodedAudioStream dec(&volume, new MP3DecoderHelix());
StreamCopy copier(dec, url);

// Function Prototypes
bool initializeFileSystem();
void saveConfigFile();
bool loadConfigFile();
void saveConfigCallback();
void configModeCallback(WiFiManager *myWiFiManager);
void initializePins();
void initializeAudio();
void startConfigurationPortal();

// Pre-save callback function
void preSaveConfigCallback() {
    Serial.println("Pre-save callback triggered");
    // Perform any operations before saving, such as checking or modifying values
    shouldSaveConfig = true;
    // Optionally modify any parameters before saving (e.g., update URL)
    // Serial.println("Stream URL: ");
    // Serial.println(streamURL); // You can print or modify values
}

void setup() {
    Serial.begin(115200);

    // Initialize File System
    if (!initializeFileSystem()) {
        Serial.println("Failed to initialize or format the file system. Restarting...");
        ESP.restart();
    }

    // Load Configuration
    bool forceConfig = !loadConfigFile();
    if (forceConfig) {
        Serial.println("Forcing configuration mode due to missing or invalid config.");
    }

    // Initialize button pin
    pinMode(BUTTON_PIN, INPUT_PULLUP);

    // Check if button is pressed at boot
    if (digitalRead(BUTTON_PIN) == LOW) {
        forceConfig = true;
    }

    // Audio Logger
    //AudioLogger::instance().begin(Serial, AudioLogger::Info);

    // Setup WiFi Manager
    WiFi.mode(WIFI_STA);
    wm.setSaveConfigCallback(saveConfigCallback);
    wm.setSaveParamsCallback(saveConfigFile);
    wm.setAPCallback(configModeCallback);
    wm.addParameter(&customTextBox);

    if (forceConfig) {
        if (!wm.startConfigPortal()) {
            Serial.println("Failed to connect and hit timeout. Restarting...");
            delay(3000);
            ESP.restart();
        }
    } else {
        if (!wm.autoConnect()) {
            Serial.println("Failed to connect and hit timeout. Restarting...");
            delay(3000);
            ESP.restart();
        }
    }

    // WiFi Connected
    Serial.println("WiFi connected");
    Serial.print("IP address: ");
    Serial.println(WiFi.localIP());

    // Save Configuration if needed
    if (shouldSaveConfig) {
        saveConfigFile();
    }

    // Initialize Pins
    initializePins();

    // Initialize I2S and Volume
    initializeAudio();

    // Start Streaming
    if (!url.begin(streamURL, "audio/mp3")) {
        Serial.println("Failed to start streaming. Check the URL.");
    }
}

void initializePins() {
    pinMode(WIFI_LED_PIN, OUTPUT);
    pinMode(AMP_CONTROL_PIN, OUTPUT);
    pinMode(MUSIC_LED_PIN, OUTPUT);
    pinMode(VOLUME_CONTROL_PIN, INPUT);
    digitalWrite(AMP_CONTROL_PIN, HIGH); // Ensure amplifier is on initially

    while (WiFi.status() != WL_CONNECTED) {
        digitalWrite(WIFI_LED_PIN, LOW);
        delay(500);
    }
    // If we exited the loop, it means we have successfully connected to WiFi
    digitalWrite(WIFI_LED_PIN, HIGH);
}

void initializeAudio() {
    auto config = i2s.defaultConfig(TX_MODE);
    config.pin_ws = 6;
    config.pin_bck = 5;
    config.pin_data = 7;
    i2s.begin(config);
    dec.begin();

    auto volumeConfig = volume.defaultConfig();
    volumeConfig.copyFrom(config);
    volume.begin(volumeConfig);
    volume.setVolume(0.5);
}

void startConfigurationPortal() {
    WiFiManager wm;
    wm.setAPCallback(configModeCallback);

    if (!wm.startConfigPortal("MyConfigPortal")) {
        Serial.println("Failed to connect. Restarting...");
        delay(3000);
        ESP.restart();
    }

    Serial.println("Configuration portal completed.");
}


void loop() {
    // Update Volume
    static float lastVolume = -1.0;
    float potValue = (1.0 - (analogRead(VOLUME_CONTROL_PIN) / 4095.0)) * 0.9;
    if (abs(potValue - lastVolume) > 0.01) {
        volume.setVolume(potValue);
        lastVolume = potValue;
        Serial.printf("Volume set to: %.2f\n", potValue);
    }

    // Stream Audio
    bool isPlaying = copier.copy();
    digitalWrite(MUSIC_LED_PIN, isPlaying ? HIGH : LOW);
}

bool initializeFileSystem() {
    if (!LittleFS.begin(false)) {
        Serial.println("File system not initialized. Formatting...");
        if (!LittleFS.format() || !LittleFS.begin()) {
            Serial.println("Failed to format or mount file system.");
            return false;
        }
    }
    if (LittleFS.exists(JSON_CONFIG_FILE)) {
        Serial.println("Configuration file found.");
        return true;
    } else {
        Serial.println("Configuration file not found. Creating default configuration...");
        saveConfigFile();
        return true;
    }
}

void saveConfigFile() {
    Serial.println("Saving configuration...");
    
    // Copy user-provided stream URL
    strncpy(streamURL, customTextBox.getValue(), sizeof(streamURL));
    Serial.print("Stream URL: ");
    Serial.println(streamURL);
    
    StaticJsonDocument<512> json;
    json["streamURL"] = streamURL;
    File configFile = LittleFS.open(JSON_CONFIG_FILE, "w");
    if (!configFile) {
        Serial.println("Failed to open config file for writing.");
    } else {
        if (serializeJson(json, configFile) == 0) {
            Serial.println("Failed to write to config file.");
        }
        configFile.close();
    }
}

bool loadConfigFile() {
    if (LittleFS.begin(false) || LittleFS.begin(true)) {
        if (LittleFS.exists(JSON_CONFIG_FILE)) {
            File configFile = LittleFS.open(JSON_CONFIG_FILE, "r");
            if (configFile) {
                StaticJsonDocument<512> json;
                if (!deserializeJson(json, configFile)) {
                    strcpy(streamURL, json["streamURL"]);
                    return true;
                }
            }
        }
    }
    return false;
}

void saveConfigCallback() {
    Serial.println("Should save config.");
    shouldSaveConfig = true;
}

void configModeCallback(WiFiManager *myWiFiManager) {
    Serial.println("Entered Configuration Mode.");
    Serial.print("Config SSID: ");
    Serial.println(myWiFiManager->getConfigPortalSSID());
    Serial.print("Config IP Address: ");
    Serial.println(WiFi.softAPIP());
}

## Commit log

2024-01-07 Added potentiometer and fixed amplifiers
    [internet-radio-speaker.kicad_sch, mcu.kicad_sch]
2024-01-24 Finished rev 1 of the board
    [DRC0010J.stp, ESP32-C3-MINI-1-N4.step, ESP32C3.step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]
2024-01-25 added screenshots, added readme and licence
    [internet-radio-speaker.kicad_pcb]
2024-09-24 updated to rev 3
    [901-143-6RFX.stp, RK0971111-L20.STEP, amp.kicad_sch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]
2025-05-07 updated to rev 4
    [amp.kicad_sch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]
2025-05-07 added firmware file for arduino
2025-05-07 Updated to KiCad 9
    [amp.kicad_sch, internet-radio-speaker.kicad_pcb, internet-radio-speaker.kicad_sch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]
2026-06-30 added schematic pdf
